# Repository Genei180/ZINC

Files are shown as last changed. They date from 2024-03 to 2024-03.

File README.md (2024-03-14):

# ZINC

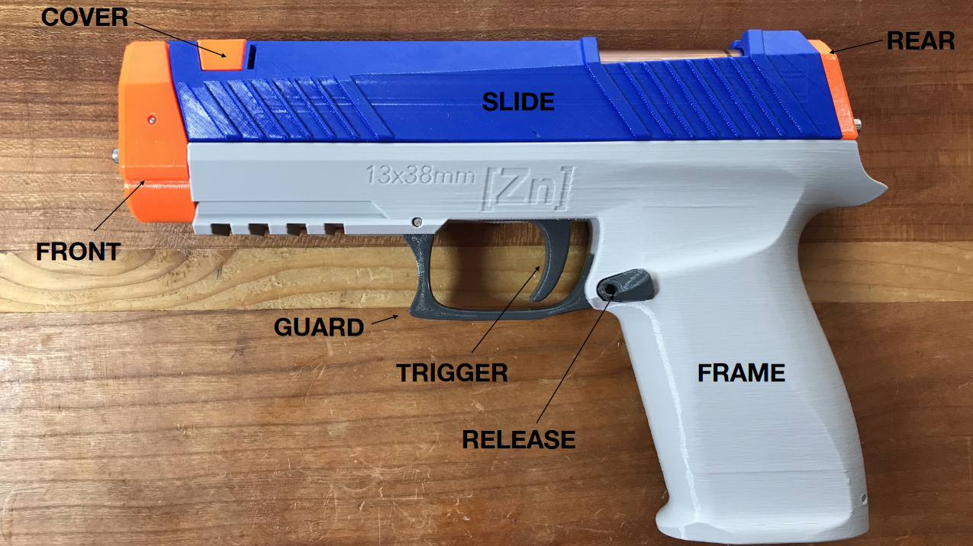
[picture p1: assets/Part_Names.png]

This is a 3D Printed Nerf Gun.
A great Project for Getting in the World of 3D Printing.

# Parts List

## Printed Parts
All Printed Parts are Provided as .step and .stl [All Zinc Files](Zinc_Files/Current/).
You Most Likly need the STL Files Provided here: [STL's](Zinc_Files/Current/STL/)

## Hardware Kit
Visit https://www.frontlinefoam.com/product/zinc-hardware-kit/ to purchase a hardware kit. 
This will Help Support 118 Design make more Awesome Designs like this.

If you buy this, you are Done with the Parts List.
Its as Easy as this.

Alternativly you can look at the Bill of Materials (BOM) for Metric Parts Provided in the Following Paragraph.

### Is it Worth it?
It is Cheaper too Buy it as Kit and you will Support the original Designer.
Reason beeing that 118 Design can buy it and Bulk and therfore get cheaper Prices.
(Even, with 30€ Additional Shipping Cost it will be Cheaper Trust me i tried it ;)
Additonally you will Safe yourself a **lot** of Trouble and Time Sourcing the Hardware.

You have been Warned.

A Bill of Materials (BOM) for Metric Parts is provided [here](BOM_Metric.md).

## 118 Design
All files licensed under Creative Commons CC BY-NC-SA.
Visit www.118.design for more information.

NOT FOR COMMERCIAL USE

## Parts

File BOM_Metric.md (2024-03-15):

## Tools Needed
- Silikon Oil (Lubing)
- Thread Cutting Set (for Plunger Rod)
- Drill Bits (Recutting Holes)
- Metal Saw (Cutting Barrel and Chamfer too Size)
- Pliers (cant Hurt too have them)

## Materials
### 3D Print Materials
- PLA (+) Filament
- Alternative (PETG)

### 3D Printed Parts
- See [Parts](ZINC_Files/Current/) for Parts you need too Print (If you are using this BOM you need the _Metric Parts, for more Information see [^MetricInfo])

### Hardware
- Plunger Tube (28mm OD[^OD], ~~25mm~~ 24mm ID[^ID], Length 152mm) See: [^MetricInfo]
- Barrel (16mm OD[^OD], 13mm ID[^ID], Length 133mm, Chamfer one side)

- Plunger Rod (M3) 3mm OD[^OD], Length 186mm
- Metal Plunger Core (can be Printed) (CNC Pull Stud) (BT30-90W)

- M2 (2mm) Pins
	- 10mm (Plug for Magazin Eject)
	- 2x 28mm (Holds Sear & Guard)
- M4 (4mm) Pin 
	- 10mm (Plug for Magazin Eject)

- M3 Screws
	- 1x 8mm (Holds the Cover)
	- 4x 12mm (Holds Front, Rear)

- 4x M3 Nut
- 2x M3 Spacer Disk

- Thumb Nut (M3)
- 2x Magnets (6mm OD[^OD], 6mm Height)

- O- Rings
	- 5mm Dia x 2mm Thickness (Plunger Impact Dampener)
	- 8mm Dia x 2mm Thickness (Chamber Seal)
	- 18mm Dia x 2.5mm Thickness (Plunger Seal)
	- 18mm Dia x 2mm Thickness (Rear Seal)

[^OD]: OD = Outer Diameter
[^ID]: ID = Inner Diameter

[^MetricInfo]: If you are Buying the Hardware Kit Ignore the _Metric Parts.
	If you want too Source Metric Hardware yourself, the Tube would have the approximate Size 28mm OD, 25mm ID.
	It seems difficult to Obtain an Acrylic Tube with 1.5mm Wall Thickness. Most Common Options have 2mm Wall Thickness.
	Therfore when 3D Printing Parts with this BOM the _Metric Variant has been Adapted for this Case. 

### Springs
- Trigger Spring (Wire Dia 1mm, OD 19mm, Length 20mm)
- Main Spring (wire dia 2mm, OD 24mm, will need to cut this to 131mm length)
- Mag / Ladder  Spring
- Sear / Torsion Spring (6 laps 120degrees, 0.4 wire dia, 4mm outer diamter)

The following Springs can be obtained by cannibalizing ballpoint pens
- Mag Release Spring (wire Dia 0.4, outer Dia 4mm, length 50mm)
- 2x Catch Spring (wire Dia 0.4, outer Dia 4mm, length 25mm)(Half one Ballpoint Pen Spring)
- Eject Spring (wire Dia 0.4, outer Dia 4mm, length 50mm)

#### Spring Manufacturing:
If you want to Manufacture your own, you additionally need the Following Spring Wire Diameters
- Wire 1mm
- Wire 2mm
- Wire 0.4mm

**Compression Springs**
Main Spring:
- OD 23mm, 2mm Wire Dia, 130mm Length
- Jig for Making it:  [Onshape 3D Printable Spring Jig Maker](https://cad.onshape.com/documents/e9fb5a52f391135701c01d90/w/7e7d53ef100483d3ce6ebb8e/e/92716daee2aa1c10fba8abba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)

Trigger Spring:
- OD 19mm, 1mm Wire Dia, 20mm Length
- Jig for Making it: (You need a ~13.2mm Thick Mandrel)

**Sear / Torsion Springs**
- OD 4mm, 0.4 Wire Dia
- 6 laps, Opening 120 degrees Apart
- Jig for Making it: [Torsion Spring Jig](https://www.printables.com/model/110017/files)

**Mag/Ladder Spring**
- 40mm  x 14mm, 1mm Wire Dia, 80mm Length
-  Jig for Making it: [Ladder Spring Maker](https://www.thingiverse.com/thing:5025291)

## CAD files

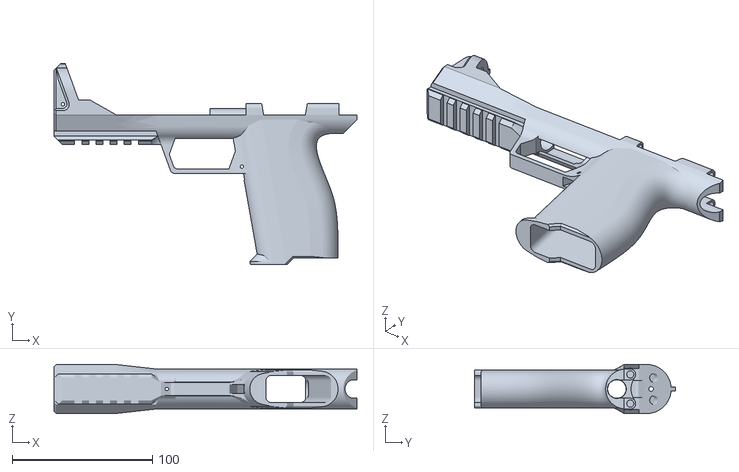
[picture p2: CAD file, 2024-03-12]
ZINC_Files/Depreciated/1.2/STL/STANDARD/FRAME_TOP_RAIL_COMPLETE_STANDARD[1.2].stl
215.9 x 143.5 x 34.9

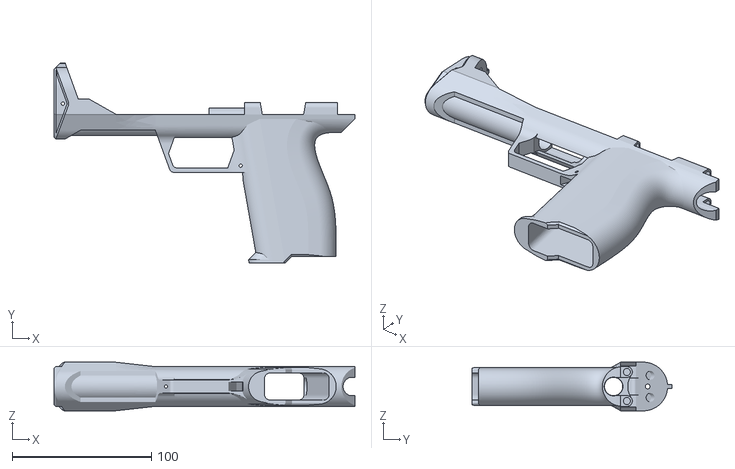
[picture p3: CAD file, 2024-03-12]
ZINC_Files/Depreciated/1.2/STL/STANDARD/FRAME_TOP_COMPACT_COMPLETE_STANDARD[1.2].stl
215.9 x 143.5 x 34.9

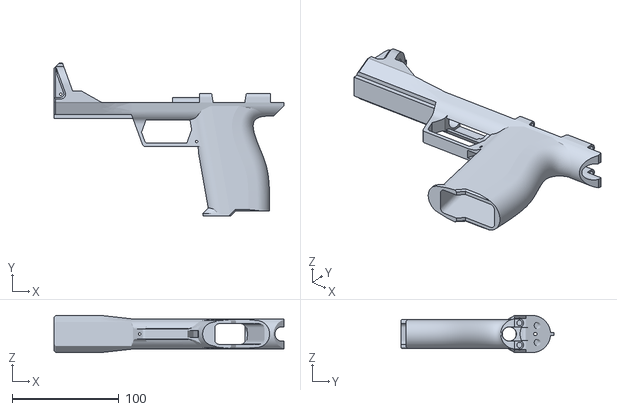
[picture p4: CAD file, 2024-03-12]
ZINC_Files/Depreciated/1.2/STL/UNDERSIZE/FRAME_TOP_RAIL_UNDERSIZE_INCOMPLETE[1.2].stl
215.9 x 143.5 x 34.9

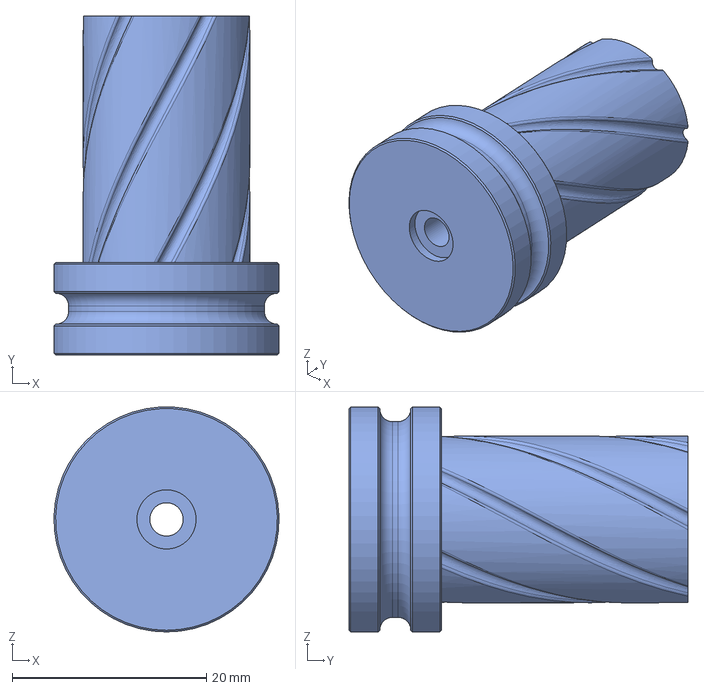
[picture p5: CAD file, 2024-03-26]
ZINC_Files/Current/STEP/PLUNGER_HIGH_POWER_METRIC[2.0].step
23.2 x 34.9 x 23.2 mm

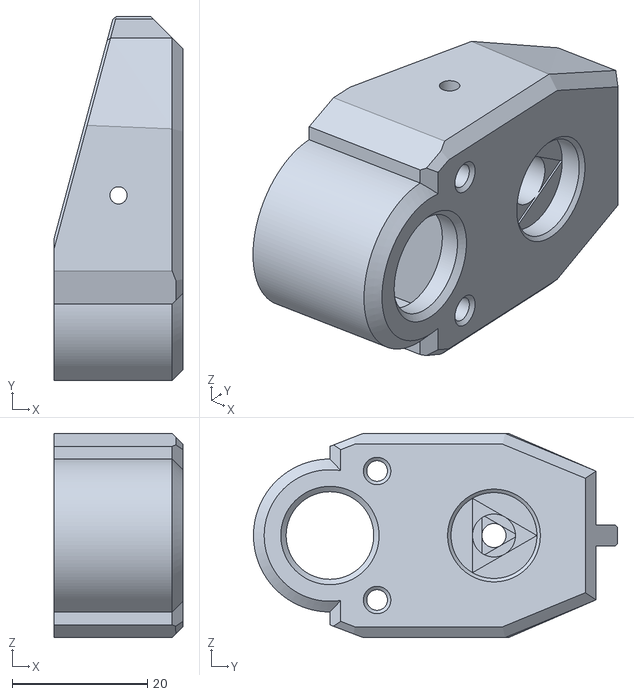
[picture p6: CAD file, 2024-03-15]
ZINC_Files/Current/STL/FRONT[2.0].stl
19.0 x 53.9 x 30.2

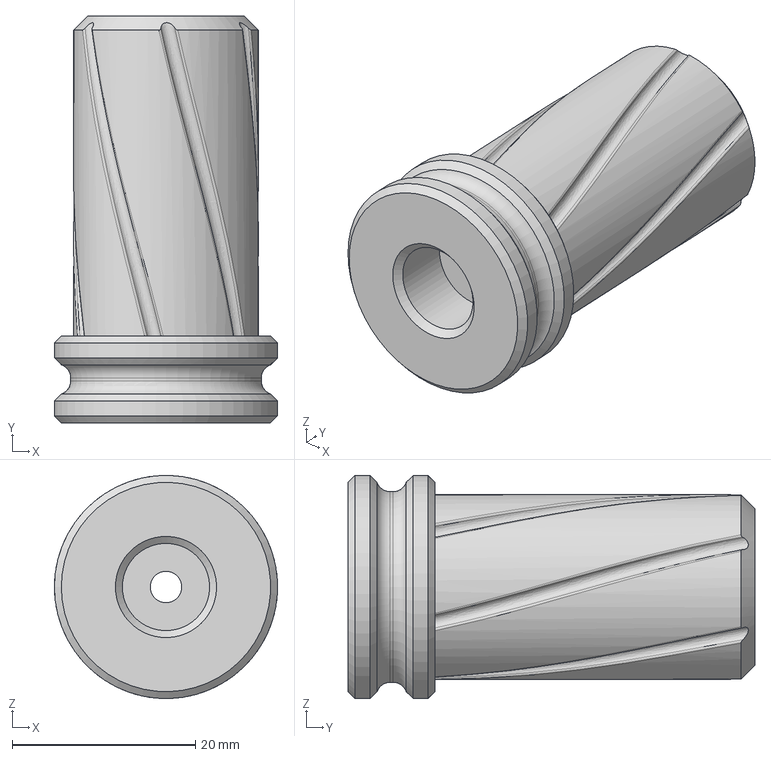
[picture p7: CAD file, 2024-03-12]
ZINC_Files/Depreciated/1.0/STEP/PLUNGER.step
24.4 x 44.4 x 24.4 mm

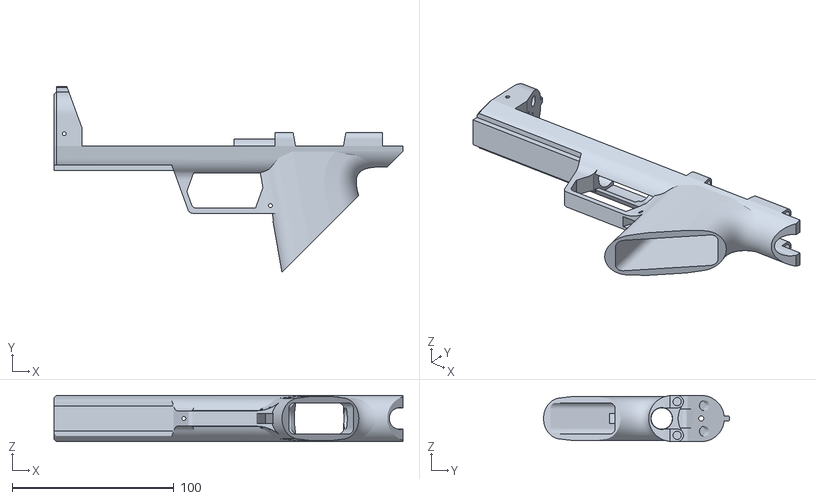
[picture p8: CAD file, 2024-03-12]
ZINC_Files/Depreciated/1.0/STL/Depreciated/FRAME_TOP_RAIL.stl
215.9 x 115.0 x 28.6

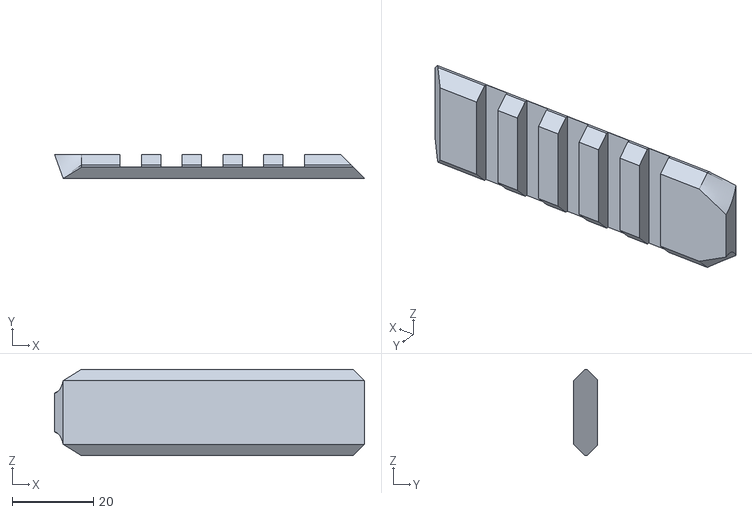
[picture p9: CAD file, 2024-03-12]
ZINC_Files/Depreciated/1.0/STL/FRAME_FRONT_RAIL.stl
76.2 x 5.88 x 21.2

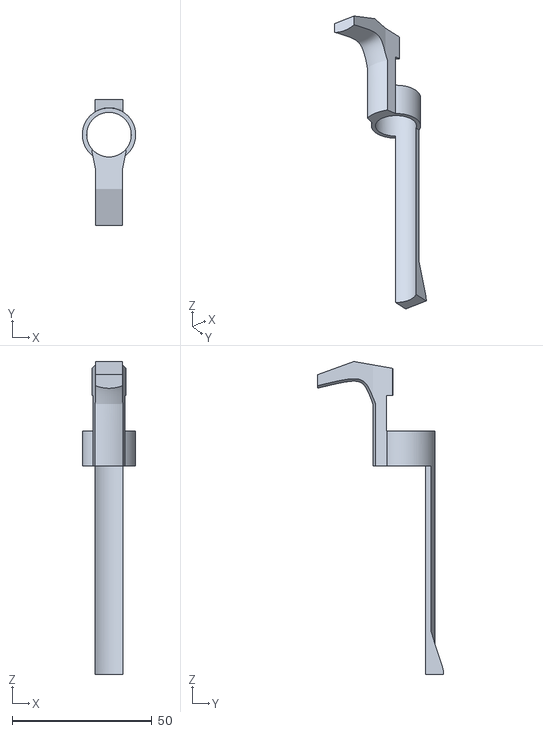
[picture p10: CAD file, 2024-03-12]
ZINC_Files/Depreciated/1.0/STL/Large Format/TRIGGER_ONE_PIECE.stl
19.1 x 45.2 x 112.1

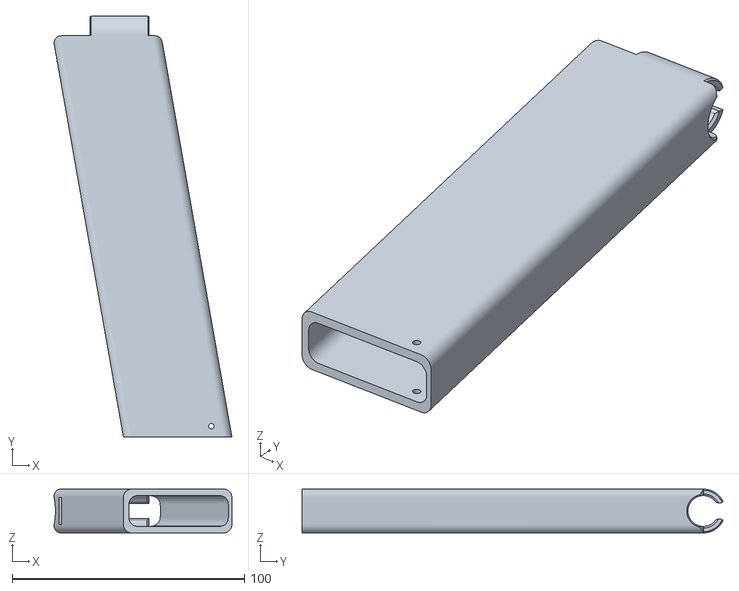
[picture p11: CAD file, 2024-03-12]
ZINC_Files/Depreciated/1.0/STL/Magazine/MAG_BODY_EXTENDED.stl
76.6 x 181.3 x 18.9

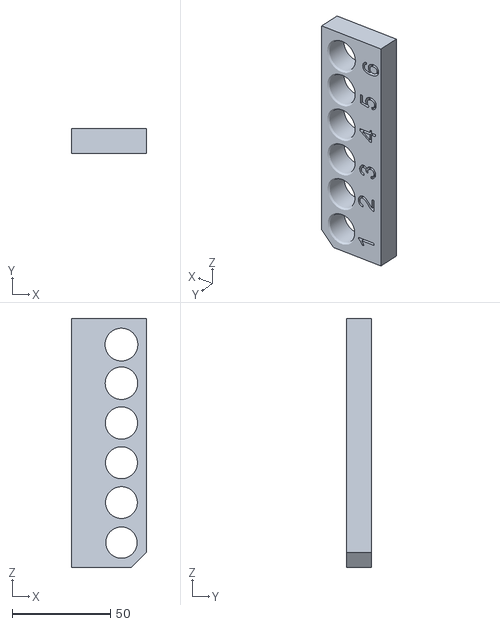
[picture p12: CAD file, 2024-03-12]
ZINC_Files/Depreciated/1.0/ZINC slicer ID test.stl
38.1 x 12.7 x 127.0

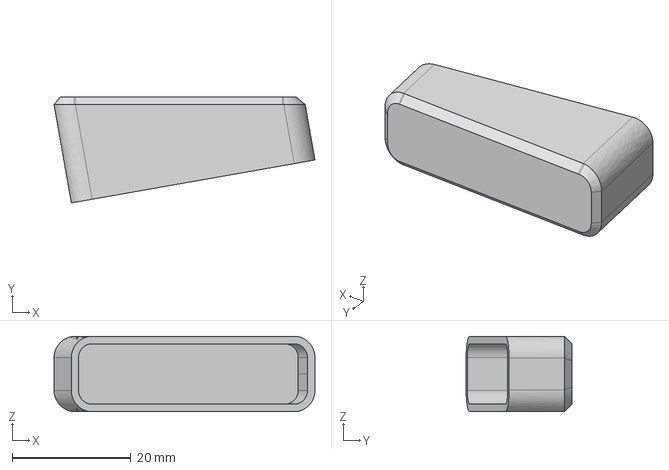
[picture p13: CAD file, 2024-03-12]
ZINC_Files/Depreciated/1.1/STEP/MAGAZINE/MAG_FOLLOWER[1.1].step
43.9 x 17.8 x 12.7 mm

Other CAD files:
ZINC_Files/Depreciated/1.1/STL/STANDARD/FRAME_TOP_RAIL_COMPLETE_STANDARD[1.1].stl
ZINC_Files/Depreciated/1.2/STL/UNDERSIZE/FRAME_TOP_RAIL_UNDERSIZE_COMPLETE[1.2].stl
ZINC_Files/Depreciated/1.1/STL/UNDERSIZE/FRAME_TOP_RAIL_COMPLETE_UNDERSIZE[1.1].stl
ZINC_Files/Depreciated/1.1/STL/OVERSIZE/FRAME_TOP_RAIL_COMPLETE_OVERSIZE[1.1].stl
ZINC_Files/Depreciated/1.2/STL/UNDERSIZE/FRAME_TOP_COMPACT_COMPLETE_UNDERSIZE[1.2].stl
ZINC_Files/Depreciated/1.1/STEP/PLUNGER[1.1].step
ZINC_Files/Current/STEP/BASE[2.0].step
ZINC_Files/Current/STEP/CATCH[2.0].step
ZINC_Files/Current/STEP/COVER[2.0].step
ZINC_Files/Current/STEP/FOLLOWER[2.0].step
ZINC_Files/Current/STEP/FRAME[2.0].step
ZINC_Files/Current/STEP/FRONT_METRIC[2.0].step
ZINC_Files/Current/STEP/GUARD_LEFT[2.0].step
ZINC_Files/Current/STEP/GUARD_RIGHT[2.0].step
ZINC_Files/Current/STEP/MAGAZINE[2.0].step
ZINC_Files/Current/STEP/MAGAZINE_10[2.0].step
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

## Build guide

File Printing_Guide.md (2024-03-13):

# DON’T RUIN THIS FOR EVERYONE.
Like any toy blaster this one, depending on its appearance & presentation, has the
potential to be mistaken for a real firearm. This blaster must be printed in bright colors
and used responsibly so that it cannot under ANY circumstances be misconstrued for
a deadly weapon. If you fail to build & use this blaster with this in mind you will
jeopardize not only your own life, but also the future of this hobby.

---
# Files licensed under Creative Commons CC BY-NC-SA.
Please visit: https://creativecommons.org/licenses/by-nc-sa/4.0/ for more d.etails

---

## Naming of Parts


### Calibration
Start by Printing the [Plunger](#Plunger) (& [Plunger-Core](#Plunger-Core), if you have no Metall one)
If those Fit fine inside each other it should work fine.

### Plunger
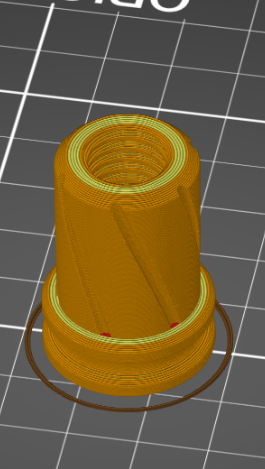
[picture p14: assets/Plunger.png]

- 2 variations, high & low power.
- 0.15mm layer height
- No supports
- 6 perimeters
- If you can’t thread the aluminum/3D Printed
plunger core into the printed part
you need to recalibrate your
printer

### Plunger-Core
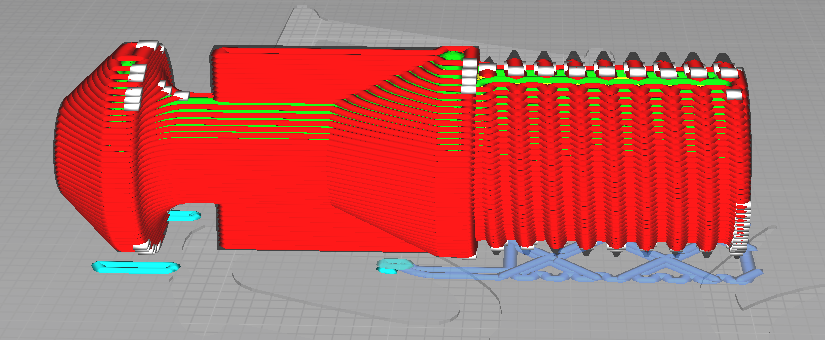
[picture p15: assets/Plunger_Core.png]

- 2 variations, high & low power.
- 0.15mm layer height
- Add Support
- 100 % Infill

This Orientation is Required, for Strength, else the Plunger Core will Breake more Easily under Tension.

### Frame
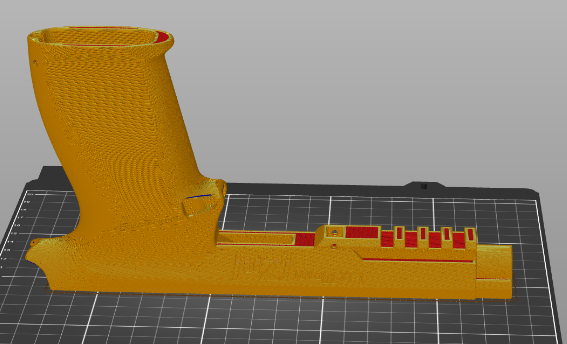
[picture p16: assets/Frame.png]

- 0.2mm Layer Height
- 6 Perimeters
- 5 Top, 5 Bottom
- 100% infill is ideal
- NO SUPPORT
- NO BRIM (Use one if absolutely necessary but
understand it will require careful clean up with an
Exacto knife)
- Ensure excellent bed adhesion, lift from the bed will
ruin the part. Use an adhesive if necessary
- PETG or PLA+
- Avoid “elephants foot”. If it is present you will need to
clean up the rails with an Exacto knife.

### Slide
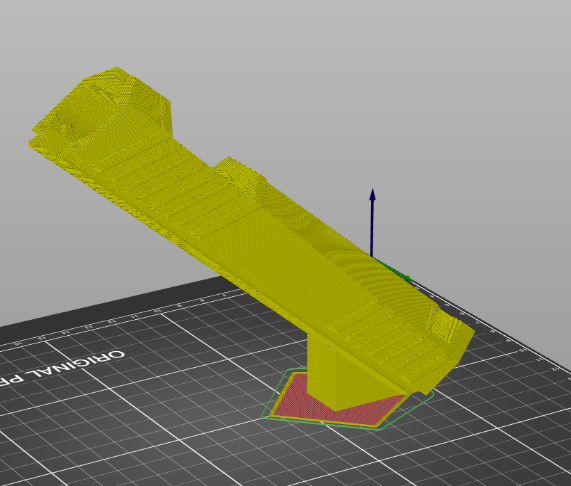
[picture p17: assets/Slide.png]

- 0.2mm Layer Height
- 6 Perimeters
- 5 Top, 5 Bottom
- 100% infill
- No Supports
- PETG recommended. This part needs to
flex to install the plunger tube.
- Ensure there is no warping: print slowly &
be mindful of how your fan shroud is
oriented.

### Catch & Sear
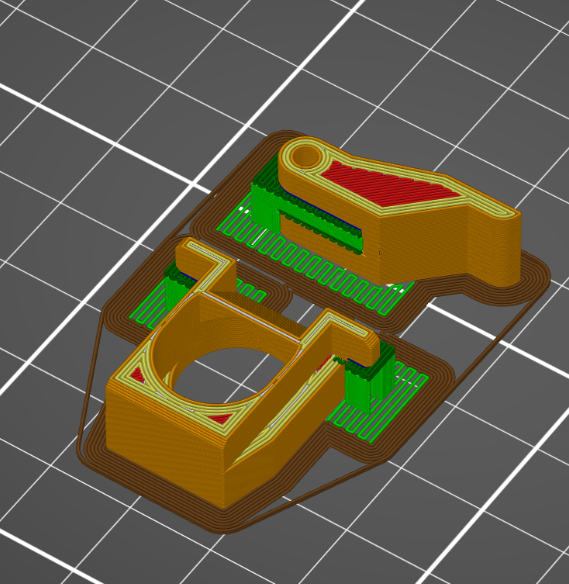
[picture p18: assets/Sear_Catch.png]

- 0.2mm Layer height
- 4 perimeters
- 100% infill
- Print with support as shown.
- PLA+ or PETG

### Front
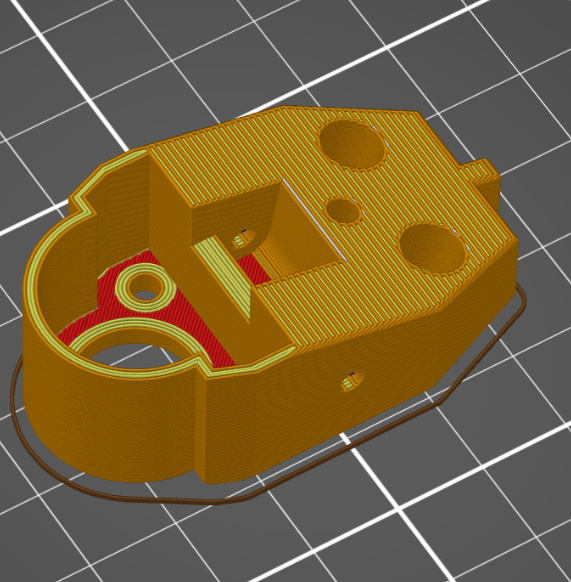
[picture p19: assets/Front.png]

- **PRINT IN HIGH-VIS ORANGE.**
- 0.2mm layer height
- 4 perimeters
- No supports
- 5 top, 5 bottom

### Trigger, Release Guard
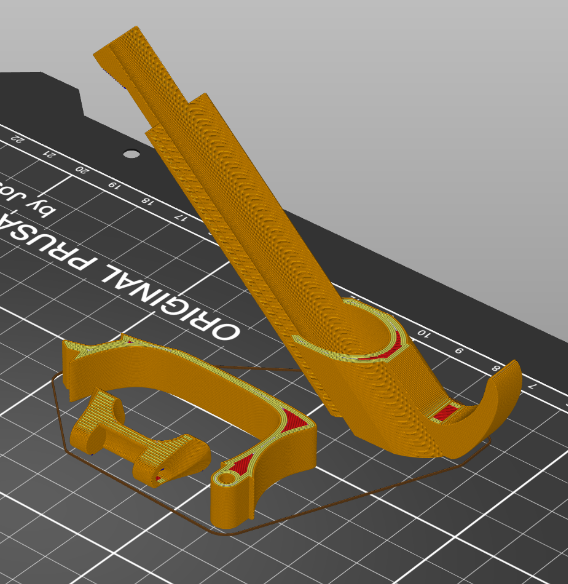
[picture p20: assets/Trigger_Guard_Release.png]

- Print the “RIGHT” variations of
GUARD and RELEASE if you are
right handed. Same for left handed.
- 0.2mm layer height (print RELEASE
at 0.1mm layer height for best
resolution)
- 6 perimeters
- Try to do this without a brim. There
will be a lot of cleanup if you need
to use one.

### Rear
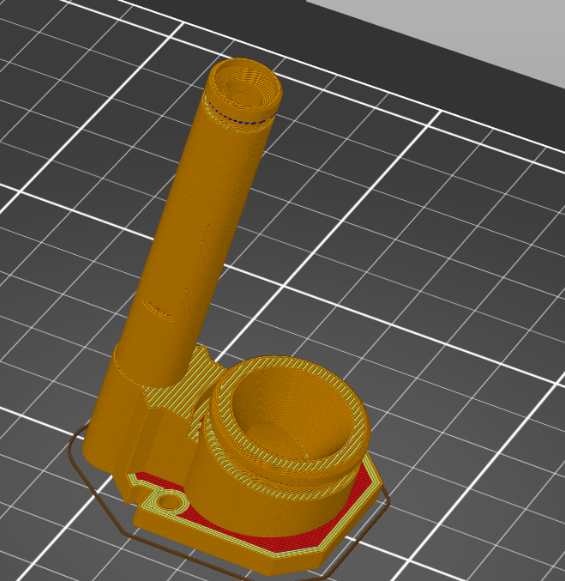
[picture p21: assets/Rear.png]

- 0.2mm Layer height
- 6 perimeters
- No supports

### Cover
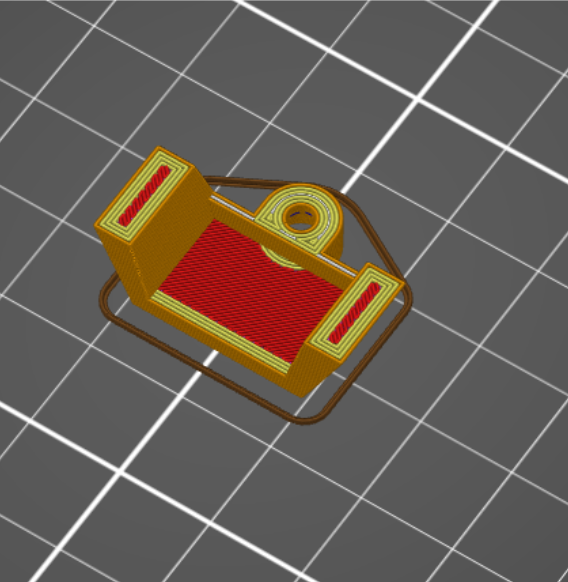
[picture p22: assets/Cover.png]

- Just print it.

### Magazin
- 0.1mm Layer Height
- 3 Perimeters
- Supports (Ideally Tree)
- (Brim for adhesion)

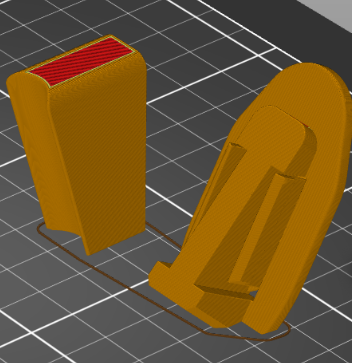
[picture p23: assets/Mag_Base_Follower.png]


Variant A:

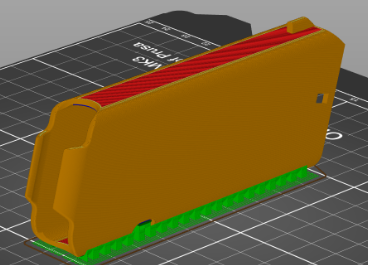
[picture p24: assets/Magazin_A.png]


Variant B:

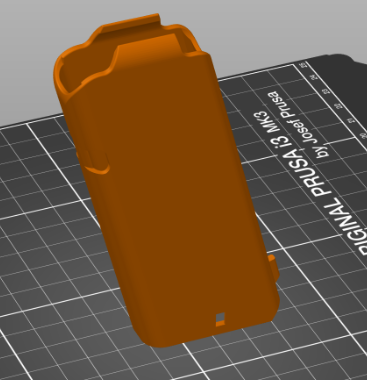
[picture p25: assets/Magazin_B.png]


Variant B will require you
to sand the magazine well to get
rid of the noise.

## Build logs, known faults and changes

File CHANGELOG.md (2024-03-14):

# ZINC Changelog

14/03/2024
    - Added Plunger Core for 3D Printing
    - Added Instruction for Plunger Core, and added the Instructions for Easier Changing in the Future as Markdown
    - Add Metric Parts
    - Add (Metric) BOM

8/12/2021
    - Assembly guide posted

8/11/2021
    - 2.0 Magazine posted
    - Magazine release updated

8/8/2021 [2.0] update. 
    - New files, guides, posted. 

3/24/2021 [1.2 Beta] update. 
  - FRAME_TOP_COMPACT variant added. 
  - Dowel pins now used to align handle to frame. 
  - 2 size variants for PLUNGER added. 
  - Tolerance changes to several parts. 
  - Added 2-piece trigger files

2/22/2021 [1.1 Beta] update. 
  - TOLERANCE_GAUGE added. 
  - 3 new file branches, UNDERSIZE, STANDARD, OVERSIZE. 
  - Rev 1.1 T-Pull added. 
  - New repository file hierarchy.
  - New magazine option, UNDERSIZE for gravity drop.
  - Improved tolerances on many parts.
  - Changes to recommended print orientation for SLIDE_REAR and TRIGGER.

2/05/2021 [1.0 Beta] launch.
  - Beta launch, all files posted.

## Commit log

2024-03-12 Update Invalid Filenames
    [BASE[2.0].step, BASE[2.0].stl, CATCH.stl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]
2024-03-13 Renamed Folder according to Ending
    [BASE[2.0].step, CATCH[2.0].step, COVER[2.0].step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]
2024-03-14 Add Metric BOM
2024-03-14 Add Plunger Core
    [PLUNGER_CORE.step]
2024-03-14 Add Metric Parts
    [FRONT_METRIC[2.0].step, PLUNGER_HIGH_POWER_METRIC[2.0].step, PLUNGER_LOW_POWER_METRIC[2.0].step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]
2024-03-14 More Verbose Print Explanation for Beginners
2024-03-15 Batch Converted Step too STL Files
    [BASE[2.0].stl, CATCH[2.0].stl, COVER[2.0].stl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]
2024-03-15 Improve Printed Parts Info
2024-03-26 Fixed Wrong Extrude
    [PLUNGER_HIGH_POWER_METRIC[2.0].step, PLUNGER_LOW_POWER_METRIC[2.0].step]
